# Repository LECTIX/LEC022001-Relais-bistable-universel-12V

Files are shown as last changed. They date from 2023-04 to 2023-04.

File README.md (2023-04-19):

# LEC022001 - Relais bistable universel 12V
Fichiers sources pour le produit LEC022001

## Description du produit

Ce module est un relais bistable disposant de toutes les protections nécessaires pour être utilisé avec une tension de 12 à 16 V alternative ou continue.
Comme tous les relais bistable, une seule impulsion est nécessaire pour faire basculer les contacts inverseurs d'un côté ou de l'autre, ce qui le rend idéal pour être utilisé avec des ILS ou bien des boutons poussoirs.
- **ALIMENTATION** 12 – 16 V AC / DC.
- **2 CONTACTS INVERSEURS** indépendants (DPDT).
- **FAIBLE CONSOMMATION** de 15 mA lorsqu'une des bobines relais est alimentée.
- **POUVOIR DE COUPURE** de 2A.

## Applications

- Cantonnement analogique
- Zone de protection faller car system
- Boucle de retournement
- Extension de contact inverseurs (aiguillages, relais, interrupteurs, …)
- Gestion d'un passage à niveau

## Installation

L’installation est simple et rapide :

1. Brancher le commun au pole négatif de l'alimentation.
1. Pour chacune des bornes R et S, intercaller un interrupteur ou équivalent (ILS, pédale, capteur Hall, contact inverseur, …) entre la borne et le pole positif de l'alimentation.
1. Les contacts inverseurs du relais réagissent en fonction du bouton sur lequel on appui.

**Attention** : Il ne faut en aucun cas alimenter les 2 bornes R et S simultanément.

## Utiliser les fichiers sources pour fabriquer le produit

Il n'est **pas nécessaire de savoir souder ou d'être bon en électronique** pour se procurer ce produit. Grâce aux fichiers sources publiés ici, vous pouvez être en mesure de faire fabriquer ce produit par un sous traitant.

### Faire fabriquer chez un sous traitant

Il est aujourd'hui possible de faire fabriquer à moindre cout des cartes électroniques. Nous recommendons [JLCPCB](https://jlcpcb.com/) si vous voulez aller au moins cher. Si vous préférez un acteur européen, [eurocircuits](https://www.eurocircuits.com/) est un des acteurs reconnus.

IMAGE ALT TEXT (http://www.youtube.com/watch?v=RXGGvsUtz0c "TUTO : faire fabriquer un produit LECTIX")

1. Télécherger les sources de ce produit en cliquant sur le bouton `Code`, puis `Download ZIP`.
1. Décompresser le dossier.
1. Les fichiers pour la fabrication se trouvent dans le répertoire `hardware/prod`.
1. Se connecter sur [https://cart.jlcpcb.com/quote](https://cart.jlcpcb.com/quote)
1. Cliquer sur le bouton `Add gerber file` et sélectionner le fichier `gerbers.zip`.
1. Sélectionnez la quantité de cartes que vous souhaitez dans le champs `PCB Qty`.
1. Laisser toutes les autres options par défaut, puis cliquez sur le toggle switch en face de `PCB Assembly`, et enfin sur le bouton `confirm`.
1. Une preview de la carte électronique sans les composants doit apparaitre. Cliquez sur `NEXT`.
1. Cliquez sur le bouton `Add BOM File`, puis sélectionnez le fichier `bom.csv`
1. Cliquez sur le bouton `Add CPL File`, puis sélectionnez le fichier `pos.csv`
1. **Vérifier que tous les composants sont en stock** et bien sélectionnés, puis cliquez sur `NEXT`.
1. Une preview de la carte avec ses composants apparait. Continuer le chemin en cliquant sur `NEXT`.
1. Le prix final apparait. Sélectionnez la catégorie du produit, puis cliquez sur `SAVE TO CART`.
1. Une fois sauvegardé dans votre panier, vous pouvez valider votre commande et choisir le moyen d'acheminement. Afin de ne pas avoir à se préoccuper des frais de douane, nous vous conseillons de choisir une méthode d'expédition DDP.

Vous receverez vos cartes sous 1 à 3 semaines. 

**Nous ne sommes en aucun cas responsables des cartes qui arriveraient défectueuses ou non fonctionnelles.**

### Modifications des fichiers sources

Installez kicad 6 (ou version supérieure), et ouvrez le fichier LEC022001.kicad_pro

### Regénérer les fichiers gerber, BOM, et position (Optionnel)

Peut se faire simplement en utilisant kikit :

```
cd hardware

# generate assembly files
docker run --rm -w /kikit -v $PWD:/kikit yaqwsx/kikit kikit fab jlcpcb --assembly --no-drc --schematic LEC022001.kicad_sch --field LCSC --corrections JLCPCB_CORRECTION --nametemplate LEC022001_{} LEC022001.kicad_pcb prod/

```

## License
Tous nos fichiers sont plubliés sous la license CERN Open Hardware Licence Version 2 - Strongly Reciprocal

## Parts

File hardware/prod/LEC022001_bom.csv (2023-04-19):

Comment | Designator | Footprint | LCSC
1N4148W | D1,D2 | Diode_SMD:D_SOD-123 | C81598
Screw_Terminal_01x03_green | J1 | 0_connectors:TerminalBlock_bornier-3_P5.08mm-green | C395850
Screw_Terminal_01x03_blue | J2,J3 | 0_connectors:TerminalBlock_bornier-3_P5.08mm-blue | C395881
HFD2-012-M-L2 | K1 | 0_relays:Relay_DPDT_HFD2-xxx-M-L2 | C399484
270 | R1 | Resistor_SMD:R_0805_2012Metric | C17590

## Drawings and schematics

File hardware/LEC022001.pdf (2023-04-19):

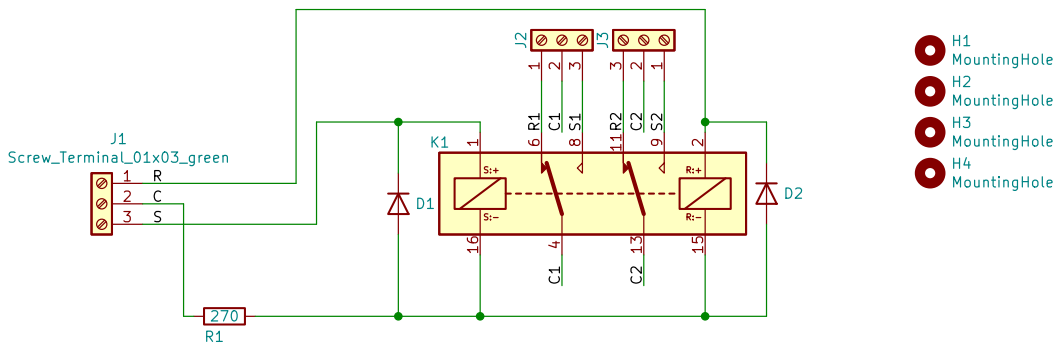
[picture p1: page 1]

Id: 1/1 Title: LEC022001 - Relais bistable universel 12V

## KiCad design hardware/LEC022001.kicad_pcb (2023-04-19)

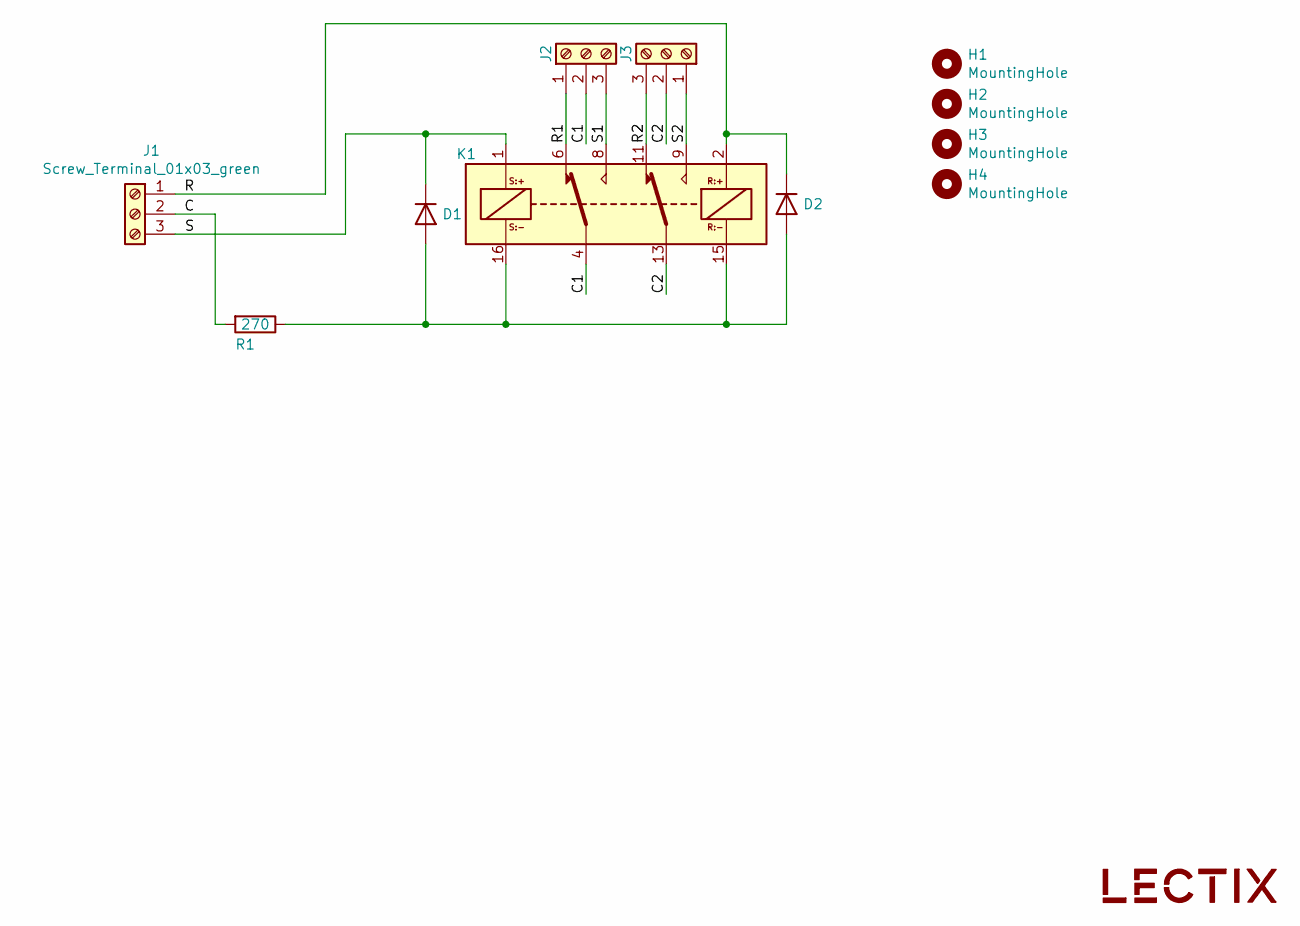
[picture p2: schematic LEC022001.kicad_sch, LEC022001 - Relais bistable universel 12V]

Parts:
D1, D2: 1N4148W; D_SOD-123; LCSC C81598
H1, H2, H3, H4: MountingHole; MountingHole_3.2mm_M3; JLCPCB BOM 0
J1: Screw_Terminal_01x03_green; TerminalBlock_bornier-3_P5.08mm-green; MPN DB126V-5.0-3P-GN; LCSC C395850
J2, J3: Screw_Terminal_01x03_blue; TerminalBlock_bornier-3_P5.08mm-blue; MPN DB301V-5.0-3P-BU-S; LCSC C395881
K1: HFD2-012-M-L2; Relay_DPDT_HFD2-xxx-M-L2; LCSC C399484
LOGO1: logo_lectix_25mm; Logo_10mm; JLCPCB BOM 0
R1: 270; R_0805_2012Metric; LCSC C17590

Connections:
/C: J1.2, R1.2
/C1: J2.2, K1.4
/C2: J3.2, K1.13
/R: D2.1 (K), J1.1, K1.2
/R1: J2.1, K1.6
/R2: J3.3, K1.11
/S: D1.1 (K), J1.3, K1.1
/S1: J2.3, K1.8
/S2: J3.1, K1.9
unnamed: D1.2 (A), D2.2 (A), K1.15, K1.16, R1.1

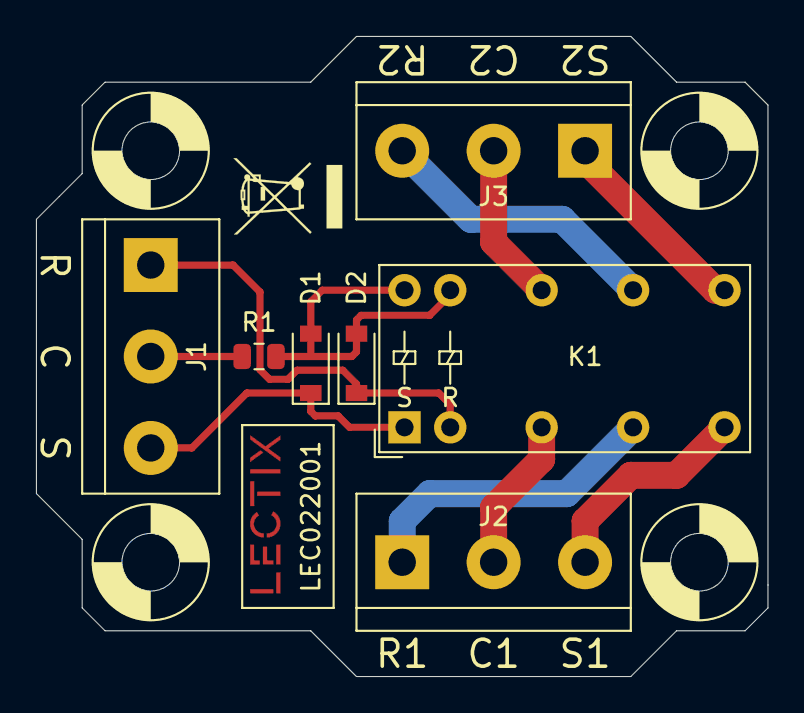
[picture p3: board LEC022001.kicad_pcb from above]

Board: 2 copper layers, 40.6 x 35.6 mm, 12 parts (0 on the bottom side), 10 nets.
